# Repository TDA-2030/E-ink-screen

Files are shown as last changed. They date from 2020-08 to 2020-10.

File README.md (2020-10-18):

# hanshow E-ink example based on ESP32

An assistant to help you view text and picture calendars. It is mainly composed of a 2.13 inch eink(epaper) and an esp32 module.

[ESP32](https://www.espressif.com/zh-hans/products/socs/esp32) of espressif is used as the controller, and development environment is [esp-idf v4.0](https://github.com/espressif/esp-idf/tree/release/v4.0).

## How to Use

1. setup environment

   [ESP-IDF Programming Guide](https://docs.espressif.com/projects/esp-idf/en/latest/esp32/get-started/index.html#installation-step-by-step) will teach you to install the development environment step by step.

2. config project

   open the menuconfig

   ```shell
   cd firmware
   idf.py menuconfig
   ```

    Here you can configure the project. For example, you can change the GPIO of the screen by entering `component config → Eink setting ` .

3. compile project

   ```shell
   idf.py build
   ```

4. download firmware

   ```shell
   idf.py -b 921600 flash monitor
   ```

   The above command will flash esp32 and open a serial monitor to show the logs of esp32.

## File Structure

```shell
.
├── datasheet  #related documents
├── firmware   #firmware of esp32
├── hardware   #PCB project of KiCAD
├── LICENSE
├── README.md
└── tools
```

## Hardware

### Resource on board

- ESP32-WROOM module
- Audio PA，can be input by PWM or DAC
- Type-C for battery charge and download firmware to ESP32
- Design of power supply with complete shutdown

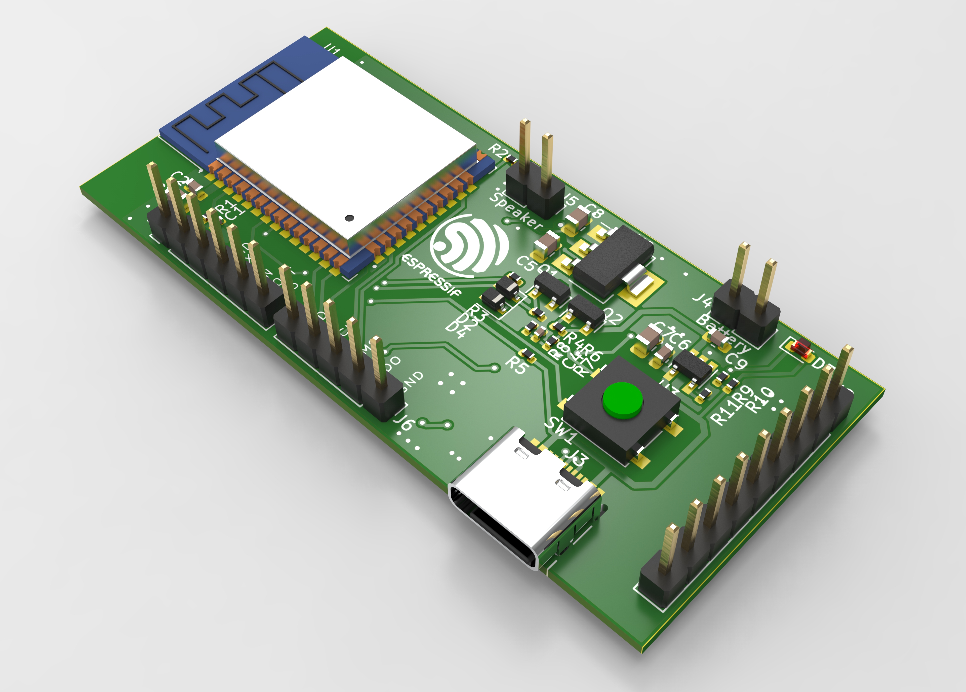
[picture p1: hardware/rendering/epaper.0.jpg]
epaper.0


### Known issues of hardware

[hardware\bugfix.md](hardware/bugfix.md)

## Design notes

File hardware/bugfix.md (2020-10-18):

- 自动下载电路的三极管封装中 B E 引脚弄反了
- 充电状态检测电路中，在 esp32 断电后 io 并不是高阻状态导致充电指示灯一直亮着，应该加下拉电阻
- 插入 USB 后应用USB供电，而不是用电池，防止充电芯片一直输出电流，导致充电灯常亮。

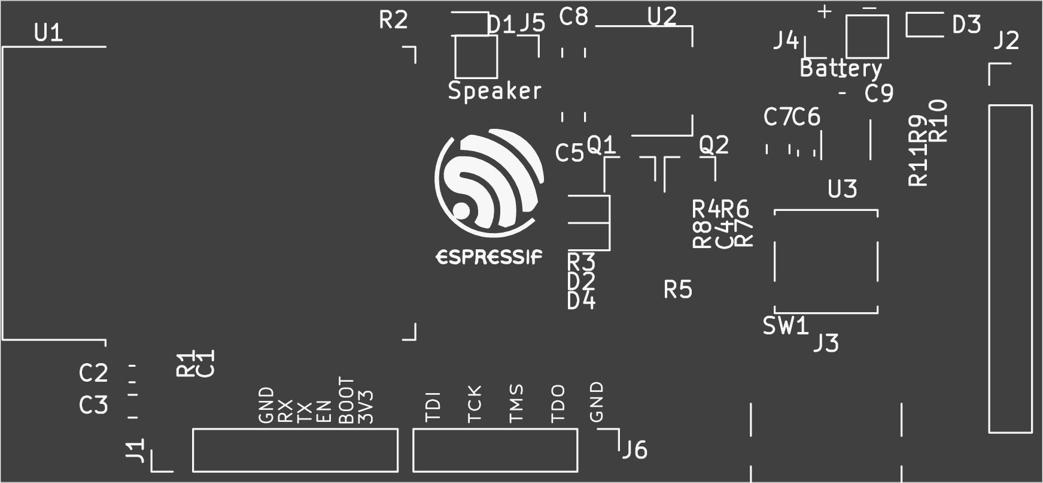
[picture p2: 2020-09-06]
hardware/rendering/epaper-F_SilkS.png

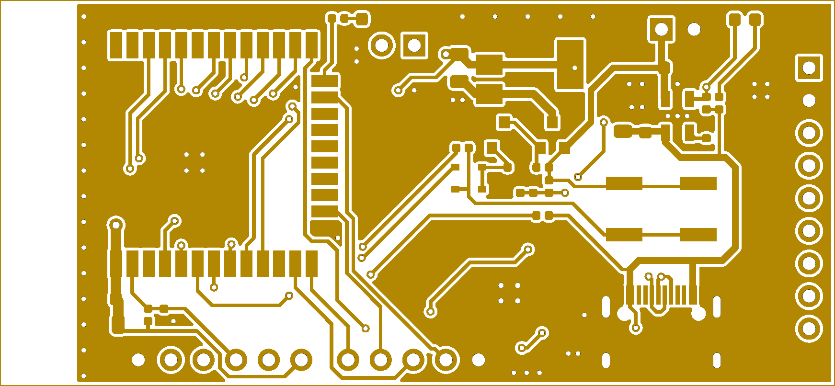
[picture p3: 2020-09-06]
hardware/rendering/epaper-F_Cu.png

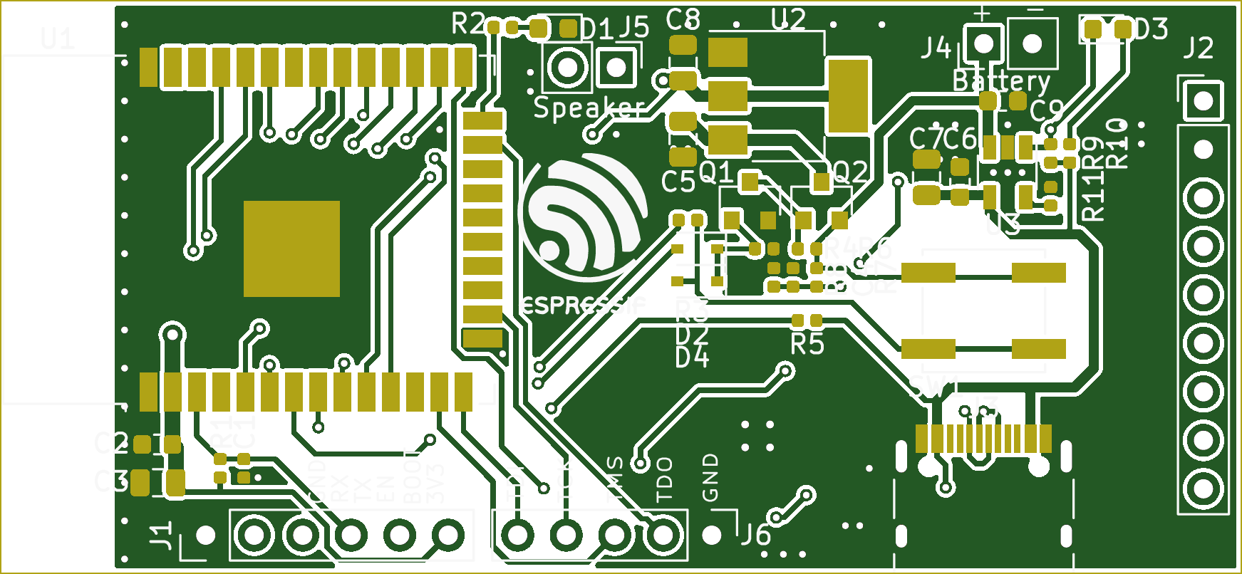
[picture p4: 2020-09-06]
hardware/rendering/epaper.png

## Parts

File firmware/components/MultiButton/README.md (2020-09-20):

# MultiButton

## 简介
MultiButton 是一个小巧简单易用的事件驱动型按键驱动模块，可无限量扩展按键，按键事件的回调异步处理方式可以简化你的程序结构，去除冗余的按键处理硬编码，让你的按键业务逻辑更清晰。

## 使用方法
1.先申请一个按键结构

```c
struct Button button1;
```
2.初始化按键对象，绑定按键的GPIO电平读取接口**read_button_pin()** ，后一个参数设置有效触发电平

```c
button_init(&button1, read_button_pin, 0);
```
3.注册按键事件

```c
button_attach(&button1, SINGLE_CLICK, Callback_SINGLE_CLICK_Handler);
button_attach(&button1, DOUBLE_CLICK, Callback_DOUBLE_Click_Handler);
...
```
4.启动按键

```c
button_start(&button1);
```
5.设置一个5ms间隔的定时器循环调用后台处理函数

```c
while(1) {
    ...
    if(timer_ticks == 5) {
        timer_ticks = 0;

        button_ticks();
    }
}
```

## 特性

MultiButton 使用C语言实现，基于面向对象方式设计思路，每个按键对象单独用一份数据结构管理：

```c
struct Button {
	uint16_t ticks;
	uint8_t  repeat: 4;
	uint8_t  event : 4;
	uint8_t  state : 3;
	uint8_t  debounce_cnt : 3;
	uint8_t  active_level : 1;
	uint8_t  button_level : 1;
	uint8_t  (*hal_button_Level)(void);
	BtnCallback  cb[number_of_event];
	struct Button* next;
};
```
这样每个按键使用单向链表相连，依次进入 button_handler(struct Button* handle) 状态机处理，所以每个按键的状态彼此独立。

## 按键事件

事件 | 说明
---|---
PRESS_DOWN | 按键按下，每次按下都触发
PRESS_UP | 按键弹起，每次松开都触发
PRESS_REPEAT | 重复按下触发，变量repeat计数连击次数
SINGLE_CLICK | 单击按键事件
DOUBLE_CLICK | 双击按键事件
LONG_PRESS_START | 达到长按时间阈值时触发一次
LONG_PRESS_HOLD | 长按期间一直触发

## Examples

```c
#include "button.h"

struct Button btn1;

int read_button1_GPIO()
{
	return HAL_GPIO_ReadPin(B1_GPIO_Port, B1_Pin);
}

int main()
{
	button_init(&btn1, read_button1_GPIO, 0);
	button_attach(&btn1, PRESS_DOWN,       BTN1_PRESS_DOWN_Handler);
	button_attach(&btn1, PRESS_UP,         BTN1_PRESS_UP_Handler);
	button_attach(&btn1, PRESS_REPEAT,     BTN1_PRESS_REPEAT_Handler);
	button_attach(&btn1, SINGLE_CLICK,     BTN1_SINGLE_Click_Handler);
	button_attach(&btn1, DOUBLE_CLICK,     BTN1_DOUBLE_Click_Handler);
	button_attach(&btn1, LONG_PRESS_START, BTN1_LONG_PRESS_START_Handler);
	button_attach(&btn2, LONG_PRESS_HOLD,  BTN1_LONG_PRESS_HOLD_Handler);
	button_start(&btn1);

	//make the timer invoking the button_ticks() interval 5ms.
	//This function is implemented by yourself.
	__timer_start(button_ticks, 0, 5);

	while(1)
	{}
}

void BTN1_PRESS_DOWN_Handler(void* btn)
{
	//do something...
}

void BTN1_PRESS_UP_Handler(void* btn)
{
	//do something...
}

...
```

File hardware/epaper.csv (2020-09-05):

Reference | Quantity | Value | Footprint | Datasheet
C1 C4 C15 | 3 | 0.1uf | Capacitor_SMD:C_0402_1005Metric | ~
C12 C10 C11 | 3 | 0.39uf | Capacitor_SMD:C_0402_1005Metric | ~
C13 | 1 | 1uf | Capacitor_SMD:C_0402_1005Metric | ~
C2 C9 C6 C14 | 4 | 1uf | Capacitor_SMD:C_0603_1608Metric | ~
C3 C7 C5 C8 | 4 | 10uf | Capacitor_SMD:C_0805_2012Metric | ~
D1 | 1 | LED_BLUE | LED_SMD:LED_0603_1608Metric | ~
D2 D4 | 2 | 1N4148WS | Diode_SMD:D_SOD-323 | https://www.vishay.com/docs/85751/1n4148ws.pdf
D3 | 1 | LED_RED | LED_SMD:LED_0603_1608Metric | ~
J1 | 1 | download | Connector_PinHeader_2.54mm:PinHeader_1x06_P2.54mm_Vertical | ~
J2 | 1 | epaper | Connector_PinHeader_2.54mm:PinHeader_1x09_P2.54mm_Horizontal | ~
J3 | 1 | USB_C_Receptacle_USB2.0 | Connector_USB:USB_C_Receptacle_HRO_TYPE-C-31-M-12 | https://www.usb.org/sites/default/files/documents/usb_type-c.zip
J4 | 1 | BATT | Connector_PinHeader_2.54mm:PinHeader_1x02_P2.54mm_Vertical | ~
J5 | 1 | Speaker | Connector_PinHeader_2.54mm:PinHeader_1x02_P2.54mm_Vertical | ~
J6 | 1 | JTAG | Connector_PinHeader_2.54mm:PinHeader_1x05_P2.54mm_Vertical | ~
Q1 | 1 | DMG3404L | Package_TO_SOT_SMD:SOT-23 | http://www.diodes.com/assets/Datasheets/DMG3404L.pdf
Q2 | 1 | AO3401A | Package_TO_SOT_SMD:SOT-23 | http://www.aosmd.com/pdfs/datasheet/AO3401A.pdf
Q3 Q4 | 2 | S8050 | Package_TO_SOT_SMD:SOT-23 | http://www.unisonic.com.tw/datasheet/S8050.pdf
R1 R9 R8 R7 R6 R4 R16 R17 R18 | 9 | 10K | Resistor_SMD:R_0402_1005Metric | ~
R10 | 1 | 1K | Resistor_SMD:R_0402_1005Metric | ~
R11 | 1 | 1.5K | Resistor_SMD:R_0402_1005Metric | ~
R15 R14 R12 R13 | 4 | 20k | Resistor_SMD:R_0402_1005Metric | ~
R19 R20 | 2 | 22 | Resistor_SMD:R_0402_1005Metric | ~
R2 R5 R3 | 3 | 4.7K | Resistor_SMD:R_0402_1005Metric | ~
SW1 | 1 | SW_Push | Button_Switch_SMD:SW_Push_1P1T_NO_CK_KSC7xxJ | ~
U1 | 1 | ESP32-WROOM-32D | RF_Module:ESP32-WROOM-32 | https://www.espressif.com/sites/default/files/documentation/esp32-wroom-32d_esp32-wroom-32u_datasheet_en.pdf
U2 | 1 | AMS1117-3.3 | Package_TO_SOT_SMD:SOT-223-3_TabPin2 | http://www.advanced-monolithic.com/pdf/ds1117.pdf
U3 | 1 | LTC4054ES5-4.2 | Package_TO_SOT_SMD:TSOT-23-5 | https://www.analog.com/media/en/technical-documentation/data-sheets/405442xf.pdf
U4 | 1 | TC8002D | Package_SO:SOIC-8_3.9x4.9mm_P1.27mm
U5 | 1 | CP2102N-A01-GQFN28 | Package_DFN_QFN:QFN-28-1EP_5x5mm_P0.5mm_EP3.35x3.35mm | https://www.silabs.com/documents/public/data-sheets/cp2102n-datasheet.pdf

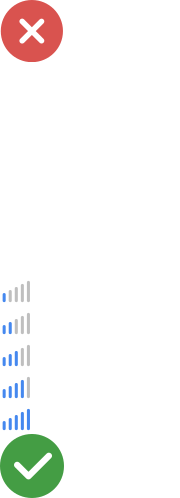
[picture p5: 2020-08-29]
firmware/components/webpage_config/html/wifi.png

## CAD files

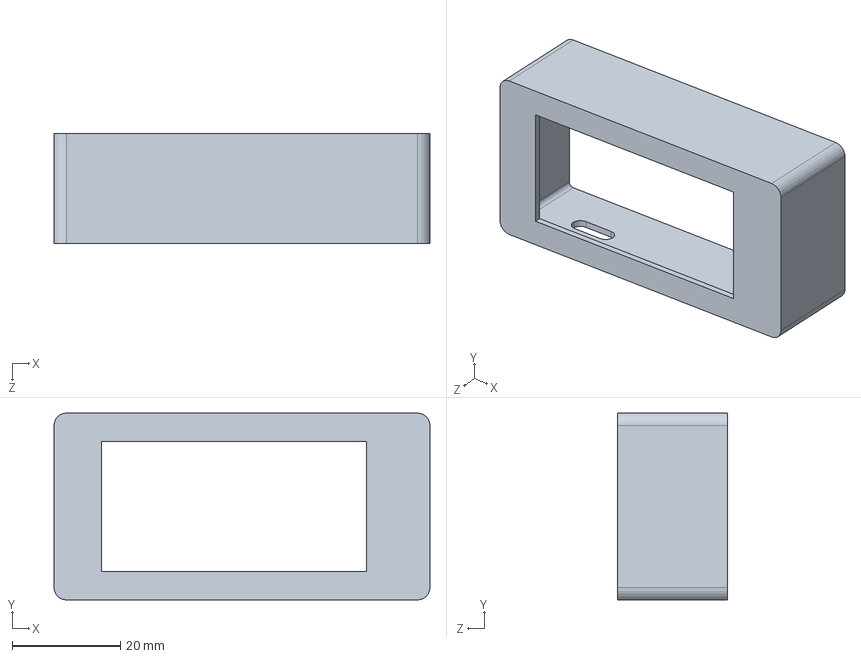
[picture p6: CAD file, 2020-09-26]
hardware/case/front.SLDPRT
69.6 x 34.6 x 20.3 mm

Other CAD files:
hardware/case/front.STL

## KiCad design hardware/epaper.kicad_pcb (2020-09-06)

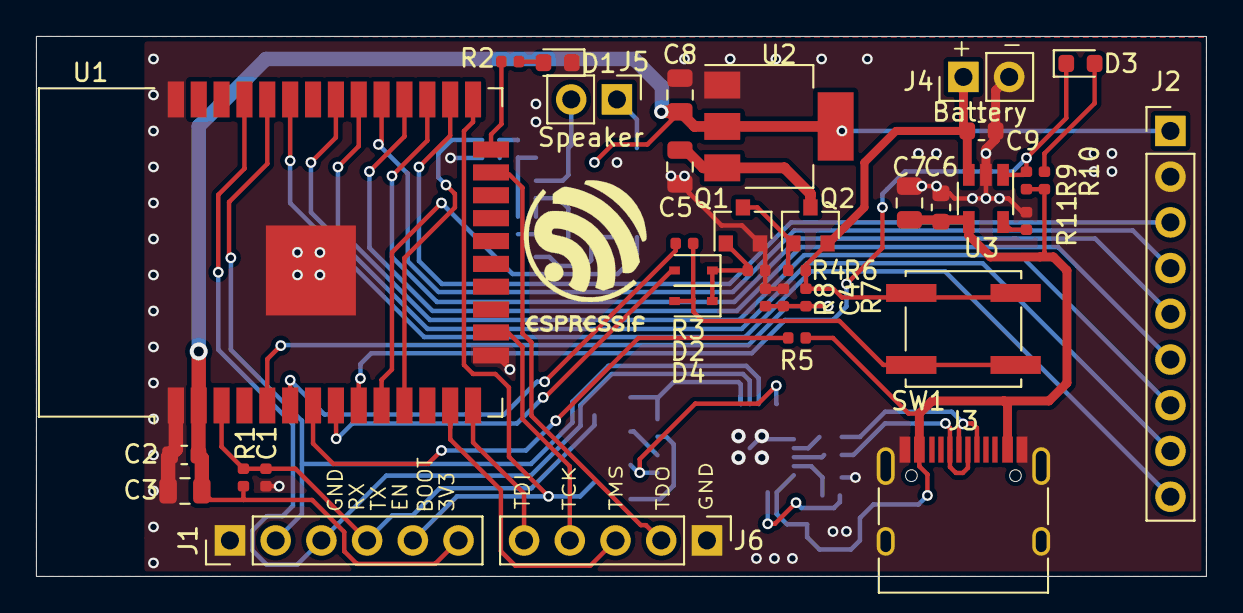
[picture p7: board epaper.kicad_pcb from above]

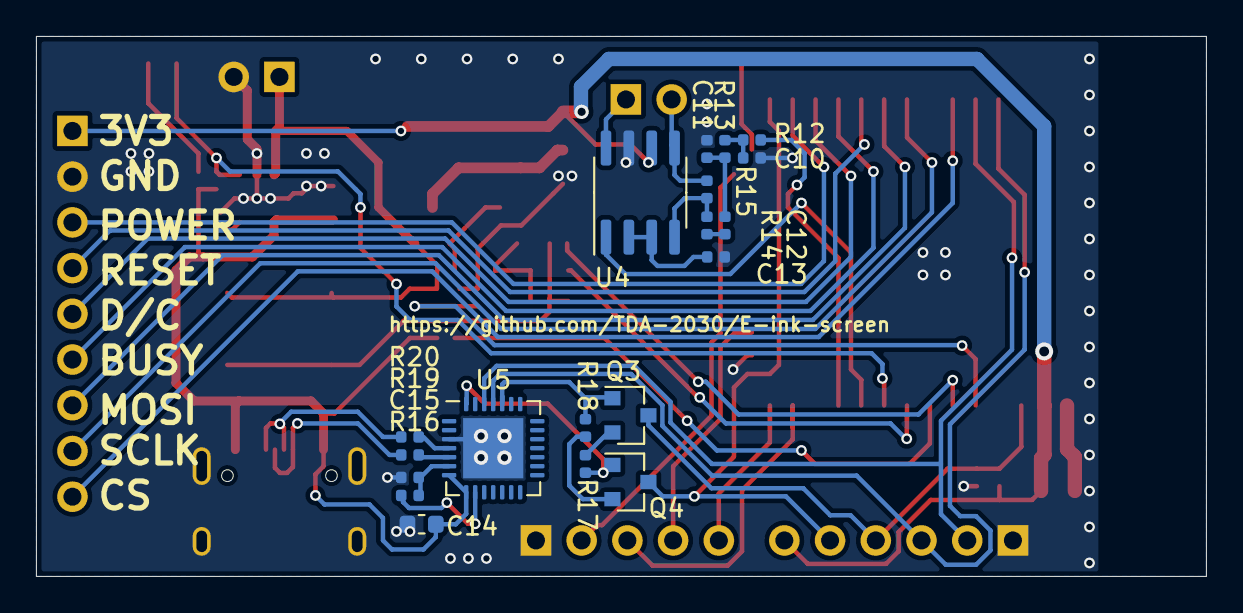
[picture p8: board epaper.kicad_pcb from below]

Board: 2 copper layers, 65.0 x 30.0 mm, 55 parts (19 on the bottom side), 51 nets.

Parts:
C1, C4, C15: 0.1uf; C_0402_1005Metric
C2, C6, C9, C14: 1uf; C_0603_1608Metric
C3, C5, C7, C8: 10uf; C_0805_2012Metric
C10, C11, C12: 0.39uf; C_0402_1005Metric
C13: 1uf; C_0402_1005Metric
D1: LED_BLUE; LED_0603_1608Metric
D2, D4: 1N4148WS; D_SOD-323
D3: LED_RED; LED_0603_1608Metric
J1: download; PinHeader_1x06_P2.54mm_Vertical
J2: epaper; PinHeader_1x09_P2.54mm_Vertical
J3: USB_C_Receptacle_USB2.0; USB_C_Receptacle_HRO_TYPE-C-31-M-12
J4: BATT; PinHeader_1x02_P2.54mm_Vertical
J5: Speaker; PinHeader_1x02_P2.54mm_Vertical
J6: JTAG; PinHeader_1x05_P2.54mm_Vertical
Q1: DMG3404L; SOT-23
Q2: AO3401A; SOT-23
Q3, Q4: S8050; SOT-23
R1, R4, R6, R7, R8, R9, R16, R17, R18: 10K; R_0402_1005Metric
R2, R3, R5: 4.7K; R_0402_1005Metric
R10: 1K; R_0402_1005Metric
R11: 1.5K; R_0402_1005Metric
R12, R13, R14, R15: 20k; R_0402_1005Metric
R19, R20: 22; R_0402_1005Metric
SW1: SW_Push; SW_Push_1P1T_NO_CK_KSC7xxJ
U1: ESP32-WROOM-32D; ESP32-WROOM-32
U2: AMS1117-3.3; SOT-223-3_TabPin2
U3: LTC4054ES5-4.2; TSOT-23-5
U4: TC8002D; SOIC-8_3.9x4.9mm_P1.27mm
U5: CP2102N-A01-GQFN28; QFN-28-1EP_5x5mm_P0.5mm_EP3.35x3.35mm

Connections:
+3V3: C2.1, C3.1, C8.1, J1.6, J2.1, R1.1, U1.2, U2.2, U4.6
+5V: C6.2, C7.2, C14.1, J3.A4, J3.A9, J3.B4, J3.B9, R5.2, R9.2, R10.2, U3.4, U5.7, U5.8
+BATT: C9.1, J4.1, Q2.2, R6.1, R7.2, SW1.2, U3.3
/ADC_VOL: C4.1, R7.1, R8.2, U1.5
/BOOT: J1.5, Q4.3, U1.25
/BUSY: J2.6, U1.28
/CS: J2.9, U1.33
/DC: J2.5, U1.27
/EN: C1.1, J1.4, Q3.3, R1.2, U1.3
/MOSI: J2.7, U1.30
/POWER: J2.3, U1.26
/RESET: J2.4, U1.29
/RXD0: J1.2, U1.34, U5.26
/SCLK: J2.8, U1.31
/Sheet5F4ECFED/BUTTON: R3.2, U1.6
/Sheet5F4ECFED/CHRG_STATE: D3.1, R9.1, U1.9, U3.1
/Sheet5F4ECFED/ENABLE: D2.2, U1.8
/Sheet5F4ECFED/USB_CHECK: R5.1, U1.7
/Sheet5F555EA7/INPUT: R12.2, U1.11
/Sheet5F555EA7/SHUTDOWN: U1.10, U4.1
/TCK: J6.4, U1.16
/TDI: J6.5, U1.14
/TDO: J6.2, U1.23
/TMS: J6.3, U1.13
/TXD0: J1.3, U1.35, U5.25
GND: C1.2, C2.2, C3.2, C4.2, C5.2, C6.1, C7.1, C8.2, C9.2, C10.1, C11.1, C13.2, C14.2, C15.1, D1.1, J1.1, J2.2, J3.A1, J3.A12, J3.B1, J3.B12, J3.S1, J4.2, J6.1, Q1.2, R4.1, R8.1, R11.1, U1.1, U1.15, U1.38, U1.39, U2.1, U3.2, U4.7, U5.3, U5.29
unnamed: C5.1, Q2.3, U2.3
unnamed: C10.2, R12.1, R13.2
unnamed: C11.2, C12.2, R13.1
unnamed: C12.1, R14.2
unnamed: C13.1, U4.2, U4.3
unnamed: C15.2, R16.2, U5.6
unnamed: D1.2, R2.1
unnamed: D2.1, D4.1, Q1.1, R4.2
unnamed: D3.2, R10.1
unnamed: D4.2, R3.1, SW1.1
unnamed: J3.A6, J3.B6, R20.2
unnamed: J3.A7, J3.B7, R19.2
unnamed: J5.1, U4.8
unnamed: J5.2, R15.1, U4.5
unnamed: Q1.3, Q2.1, R6.2
unnamed: Q3.1, R18.2, U5.24
unnamed: Q3.2, R17.1
unnamed: Q4.1, R17.2, U5.28
unnamed: Q4.2, R18.1
unnamed: R2.2, U1.24
unnamed: R11.2, U3.5
unnamed: R14.1, R15.2, U4.4
unnamed: R16.1, U5.9
unnamed: R19.1, U5.5
unnamed: R20.1, U5.4

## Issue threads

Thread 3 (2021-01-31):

请问如何 工程中的spiffs镜像如何写入到ESP32中？

givemethree, 2021-01-31:
图片和mp3如何打包spiffs镜像？镜像烧录到那个地址？   没有spiffs镜像貌似程序跑不起来 一直在重启

givemethree, 2021-01-31:
感谢楼主

TDA-2030, 2021-02-02:
我用的是 cmake 编译，`firmware/main/CMakeLists.txt` 文件的 spiffs_create_partition_image 命令会写入 spiffs 的镜像。具体用法可参考 IDF 编程指南的 [SPIFFS 文件系统](https://docs.espressif.com/projects/esp-idf/zh_CN/latest/esp32/api-reference/storage/spiffs.html#id3)

givemethree, 2021-02-03:
谢谢回复，您的意思是编译后，烧录的时候自动将镜像烧录到esp32中？

TDA-2030, 2021-02-03:
是的，自动烧录到 partition 指定的分区

givemethree, 2021-02-05:
感谢！ 刚看了下 重启是因为墨水屏在局部刷新的时候一直是忙碌的状态导致的  全局刷新的时候正常。可能是我的屏幕不支持局部刷新 导致的  我再试试

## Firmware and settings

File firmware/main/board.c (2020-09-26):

#include "esp_log.h"
#include "freertos/FreeRTOS.h"
#include "freertos/task.h"
#include "driver/gpio.h"
#include "esp_timer.h"
#include "esp_system.h"
#include "nvs_flash.h"
#include "multi_button.h"
#include "board.h"

static const char *TAG = "button";
static struct Button btn1;

#define IO_BUTTON_PIN 34
#define IO_LED_STATUS_PIN 2
#define IO_POWER_CTRL_PIN 32
#define IO_SPEAKER_EN_PIN 25
#define IO_USB_CHECK_PIN  35
#define IO_CHRG_CHECK_PIN 33

#define OUT_PINS (1ULL << IO_LED_STATUS_PIN) | (1ULL << IO_POWER_CTRL_PIN) | (1ULL << IO_SPEAKER_EN_PIN)

static uint8_t read_button1_GPIO()
{
	return gpio_get_level(IO_BUTTON_PIN);
}

static void periodic_timer_button_callback(void* arg)
{
    button_ticks();
}

static void BTN1_LONG_PRESS_START_Handler(void* btn)
{
	ESP_LOGW(TAG, "Start to erase nvs and restart!");
	nvs_flash_erase();
	esp_restart();
}

static void BTN1_power_off_cb(void *args)
{
    ESP_LOGW(TAG, "Power off!");
    vTaskDelay(100 / portTICK_RATE_MS);
    board_pa_ctrl(false);
    board_power_set(false);
}

static esp_err_t my_button_init(void)
{
	button_init(&btn1, read_button1_GPIO, 1);
	button_attach(&btn1, LONG_PRESS_START, BTN1_LONG_PRESS_START_Handler);
    button_attach(&btn1, DOUBLE_CLICK, BTN1_power_off_cb);

	button_start(&btn1);

	//make the timer invoking the button_ticks() interval 5ms.
	//This function is implemented by yourself.

	const esp_timer_create_args_t periodic_timer_args = {
            .callback = &periodic_timer_button_callback,
            /* name is optional, but may help identify the timer when debugging */
            .name = "button",
    };

    esp_timer_handle_t periodic_timer;
    esp_timer_create(&periodic_timer_args, &periodic_timer);
	return esp_timer_start_periodic(periodic_timer, 5000);
}


static void periodic_led_callback(void* arg)
{
    static bool i=1;
    gpio_set_level(IO_LED_STATUS_PIN, i);
    i=!i;
}

void board_init(void)
{
    gpio_config_t io_conf;
    io_conf.intr_type = GPIO_INTR_DISABLE;
    io_conf.mode = GPIO_MODE_OUTPUT;
    io_conf.pin_bit_mask = OUT_PINS;
    io_conf.pull_down_en = GPIO_PULLDOWN_DISABLE;
    io_conf.pull_up_en = GPIO_PULLUP_DISABLE;
    gpio_config(&io_conf);

    io_conf.mode = GPIO_MODE_INPUT;
    io_conf.pin_bit_mask = (1ULL << IO_USB_CHECK_PIN) | (1ULL << IO_BUTTON_PIN);
    io_conf.pull_down_en = GPIO_PULLDOWN_ENABLE;
    io_conf.pull_up_en = GPIO_PULLUP_DISABLE;
    gpio_config(&io_conf);

    io_conf.pin_bit_mask = (1ULL << IO_CHRG_CHECK_PIN);
    io_conf.pull_down_en = GPIO_PULLDOWN_DISABLE;
    io_conf.pull_up_en = GPIO_PULLUP_ENABLE;
    gpio_config(&io_conf);

    board_power_set(true);
    
    my_button_init();

    const esp_timer_create_args_t periodic_timer_args = {
            .callback = &periodic_led_callback,
            /* name is optional, but may help identify the timer when debugging */
            .name = "led",
    };

    esp_timer_handle_t periodic_timer;
    esp_timer_create(&periodic_timer_args, &periodic_timer);
	esp_timer_start_periodic(periodic_timer, 500000);
}

void board_power_set(uint8_t is_on)
{
    gpio_set_level(IO_POWER_CTRL_PIN, is_on ? 1 : 0);
}

esp_err_t board_pa_ctrl(bool enable)
{
    if (enable){
        gpio_set_level(IO_SPEAKER_EN_PIN, 0);
    } else {
        gpio_set_level(IO_SPEAKER_EN_PIN, 1);
    }

    return ESP_OK;
}

esp_err_t board_button_attach(PressEvent event, BtnCallback cb)
{
	button_attach(&btn1, event, cb);
	return ESP_OK;
}

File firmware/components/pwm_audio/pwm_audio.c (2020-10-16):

// Copyright 2020 Espressif Systems (Shanghai) PTE LTD
//
// Licensed under the Apache License, Version 2.0 (the "License");
// you may not use this file except in compliance with the License.
// You may obtain a copy of the License at
//
//     http://www.apache.org/licenses/LICENSE-2.0
//
// Unless required by applicable law or agreed to in writing, software
// distributed under the License is distributed on an "AS IS" BASIS,
// WITHOUT WARRANTIES OR CONDITIONS OF ANY KIND, either express or implied.
// See the License for the specific language governing permissions and
// limitations under the License.


#include <stdio.h>
#include <string.h>
#include "freertos/FreeRTOS.h"
#include "freertos/semphr.h"
#include "freertos/task.h"
#include "driver/ledc.h"
#include "esp_err.h"
#include "esp_timer.h"
#include "esp_log.h"
#include "esp_heap_caps.h"
#include "driver/timer.h"
#include "soc/timer_group_struct.h"
#include "soc/ledc_struct.h"
#include "soc/ledc_reg.h"
// #include "hal/gpio_ll.h"
// #include "soc/timer_group_caps.h"
#include "pwm_audio.h"
#include "sdkconfig.h"

#ifndef CONFIG_IDF_TARGET_ESP32S2
#ifndef CONFIG_IDF_TARGET_ESP32
#error No defined idf target esp32 or esp32s2
#endif
#endif


static const char *TAG = "pwm_audio";

#define PWM_AUDIO_CHECK(a, str, ret_val)                          \
    if (!(a))                                                     \
    {                                                             \
        ESP_LOGE(TAG, "%s(%d): %s", __FUNCTION__, __LINE__, str); \
        return (ret_val);                                         \
    }

static const char *PWM_AUDIO_PARAM_ADDR_ERROR = "PWM AUDIO PARAM ADDR ERROR";
static const char *PWM_AUDIO_FRAMERATE_ERROR  = "PWM AUDIO FRAMERATE ERROR";
static const char *PWM_AUDIO_STATUS_ERROR     = "PWM AUDIO STATUS ERROR";
static const char *PWM_AUDIO_TG_NUM_ERROR     = "PWM AUDIO TIMER GROUP NUMBER ERROR";
static const char *PWM_AUDIO_TIMER_NUM_ERROR  = "PWM AUDIO TIMER NUMBER ERROR";
static const char *PWM_AUDIO_ALLOC_ERROR      = "PWM AUDIO ALLOC ERROR";
static const char *PWM_AUDIO_RESOLUTION_ERROR = "PWM AUDIO RESOLUTION ERROR";

#define BUFFER_MIN_SIZE     (256UL)
#define SAMPLE_RATE_MAX     (48000)
#define SAMPLE_RATE_MIN     (8000)
#define CHANNEL_LEFT_INDEX  (0)
#define CHANNEL_RIGHT_INDEX (1)
#define CHANNEL_LEFT_MASK   (0x01)
#define CHANNEL_RIGHT_MASK  (0x02)
#define VOLUME_0DB          (16)

/**
 * Debug Configuration 
 **/
#define ISR_DEBUG 0  /**< INDEBUG SWITCH */
#define ISR_DEBUG_IO_MASK 0x8000

typedef struct {
    char *buf;                         /**< Original pointer */
    uint32_t volatile head;            /**< ending pointer */
    uint32_t volatile tail;            /**< Read pointer */
    uint32_t size;                     /**< Buffer size */
    uint32_t is_give;                  /**< semaphore give flag */
    SemaphoreHandle_t semaphore_rb;    /**< Semaphore for ringbuffer */

} ringBuf;
typedef ringBuf *ringbuf_handle_t;

typedef struct {
    pwm_audio_config_t    config;                          /**< pwm audio config struct */
    ledc_channel_config_t ledc_channel[PWM_AUDIO_CH_MAX];  /**< ledc channel config */
    ledc_timer_config_t   ledc_timer;                      /**< ledc timer config  */
    timg_dev_t            *timg_dev;                       /**< timer group register pointer */
    ringbuf_handle_t      ringbuf;                         /**< audio ringbuffer pointer */
    uint32_t              channel_mask;                    /**< channel gpio mask */
    uint32_t              channel_set_num;                 /**< channel audio set number */
    int32_t               framerate;                       /*!< frame rates in Hz */
    int32_t               bits_per_sample;                 /*!< bits per sample (8, 16, 32) */
    int32_t               volume;                          /*!< the volume(-VOLUME_0DB ~ VOLUME_0DB) */

    pwm_audio_status_t status;
} pwm_audio_handle;
typedef pwm_audio_handle *pwm_audio_handle_t;

/**< ledc some register pointer */
static volatile uint32_t *g_ledc_left_conf0_val  = NULL;
static volatile uint32_t *g_ledc_left_conf1_val  = NULL;
static volatile uint32_t *g_ledc_left_duty_val   = NULL;
static volatile uint32_t *g_ledc_right_conf0_val = NULL;
static volatile uint32_t *g_ledc_right_conf1_val = NULL;
static volatile uint32_t *g_ledc_right_duty_val  = NULL;

/**< pwm audio handle pointer */
static pwm_audio_handle_t g_pwm_audio_handle = NULL;

static portMUX_TYPE timer_spinlock = portMUX_INITIALIZER_UNLOCKED;

/**
 * Ringbuffer for pwm audio
 */
static esp_err_t rb_destroy(ringbuf_handle_t rb)
{
    if (rb == NULL) {
        return ESP_ERR_INVALID_ARG;
    }

    if (rb->buf) {
        heap_caps_free(rb->buf);
    }

    if (rb->semaphore_rb) {
        vSemaphoreDelete(rb->semaphore_rb);
    }

    heap_caps_free(rb);
    rb = NULL;
    return ESP_OK;
}
static ringbuf_handle_t rb_create(uint32_t size)
{
    if (size < (BUFFER_MIN_SIZE << 2)) {
        ESP_LOGE(TAG, "Invalid buffer size, Minimum = %d", (int32_t)(BUFFER_MIN_SIZE << 2));
        return NULL;
    }

    ringbuf_handle_t rb = NULL;
    char *buf = NULL;

    do {
        bool _success =
            (
                (rb             = heap_caps_malloc(sizeof(ringBuf), MALLOC_CAP_8BIT | MALLOC_CAP_INTERNAL)) &&
                (buf            = heap_caps_malloc(size, MALLOC_CAP_8BIT | MALLOC_CAP_INTERNAL))   &&
                (rb->semaphore_rb   = xSemaphoreCreateBinary())

            );

        if (!_success) {
            break;
        }

        rb->is_give = 0;
        rb->buf = buf;
        rb->head = rb->tail = 0;
        rb->size = size;
        return rb;

    } while (0);

    rb_destroy(rb);
    return NULL;
}

static uint32_t IRAM_ATTR rb_get_count(ringbuf_handle_t rb)
{
    uint32_t tail = rb->tail;

    if (rb->head >= tail) {
        return (rb->head - tail);
    }

    return (rb->size - (tail - rb->head));
}

static uint32_t IRAM_ATTR rb_get_free(ringbuf_handle_t rb)
{
    /** < Free a byte to judge the ringbuffer direction */
    return (rb->size - rb_get_count(rb) - 1);
}

static esp_err_t rb_flush(ringbuf_handle_t rb)
{
    rb->tail = rb->head = 0;
    return ESP_OK;
}

static esp_err_t IRAM_ATTR rb_read_byte(ringbuf_handle_t rb, uint8_t *outdata)
{
    uint32_t tail = rb->tail;

    if (tail == rb->head) {
        return ESP_FAIL;
    }

    // Send a byte from the buffer
    *outdata = rb->buf[tail];

    // Update tail position
    tail++;

    if (tail == rb->size) {
        tail = 0;
    }

    rb->tail = tail;
    return ESP_OK;
}

static esp_err_t rb_write_byte(ringbuf_handle_t rb, const uint8_t indata)
{
    // Calculate next head
    uint32_t next_head = rb->head + 1;

    if (next_head == rb->size) {
        next_head = 0;
    }

    if (next_head == rb->tail) {
        return ESP_FAIL;
    }

    // Store data and advance head
    rb->buf[rb->head] = indata;
    rb->head = next_head;
    return ESP_OK;
}
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

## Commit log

2020-08-29 feat: add web file server
    [partitions.csv]
2020-08-29 fix(file_server): add cpp condition
    [file_manage.c]
2020-08-31 pcb: add schematic files
    [epaper.kicad_pcb, epaper.sch, power.sch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]
2020-09-02 feat(pcb): add pcb design
    [epaper.sch, power.sch]
2020-09-03 feat(pcb): add pcb line design
    [epaper.kicad_pcb, epaper.sch, power.sch]
2020-09-05 feat(pcb): compeleted pcb line design
    [SW3dPS-TACT Switch - SKHUAME010.STEP, USB_Type_C_6pin.STEP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]
2020-09-06 refactor: adjust file structure
    [epaper-B_Cu.gbl, epaper-B_Mask.gbs, epaper-B_Paste.gbp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]
2020-09-06 fix: modify default edpio config to adapt pcb
2020-09-06 feat: add PCB 3D rendering resource
2020-09-26 fix(main): add board.c to control peripheral on board like button led
    [board.c]
2020-09-26 hardware: add case model for 3D printer
    [front.SLDPRT, front.STL]
2020-09-26 fix(epd2in13): replace c++ code with c
    [partitions.csv]
2020-09-26 fix(epd2in13): add API Epd_Set_LUT
    [epd2in13.c, epd2in13.h]
2020-09-26 feat(main): add power off action with double click button
2020-10-15 fix(pwm_audio): fix abnormal of pwm_audio
    [partitions.csv]
2020-10-18 fix: restore cmakelist.txt and modify show image interval
    [epd2in13_gd.c]
2020-10-18 fix(epd2in13): fix epaper driver
    [epd2in13.c]
2020-11-07 fix(firmware): modify partition table
    [partitions.csv]
2024-12-02 update for support esp32-c6 board
